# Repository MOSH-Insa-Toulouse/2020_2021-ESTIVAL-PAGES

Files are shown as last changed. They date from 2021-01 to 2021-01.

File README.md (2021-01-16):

# LoRa Project: Smart Gas Sensor

This project is realised in the 5th year PTP ISS at INSA Toulouse. A **LoRa-connected gas sensor** has been developed to alert the user about the concentration of health threatening gas near the sensor.

# Content

This repository contains: 
* KiCad PCB files: A shield for the gas sensor to plug on an Arduino Uno (made with KiCad)
* The datasheet: Complete datasheet for the gaz sensor

## KiCad PCB Files

### Overview
The shield is composed of :

* A home-made gas sensor (made at AIME)
* An amplifier stage for home-made gas sensor
* A commercial gas sensor for the calibration of the home-made one (Grove connectors)
* A LoRa chip for the data transmission
* A LED as an on/off indicator

### Schematics
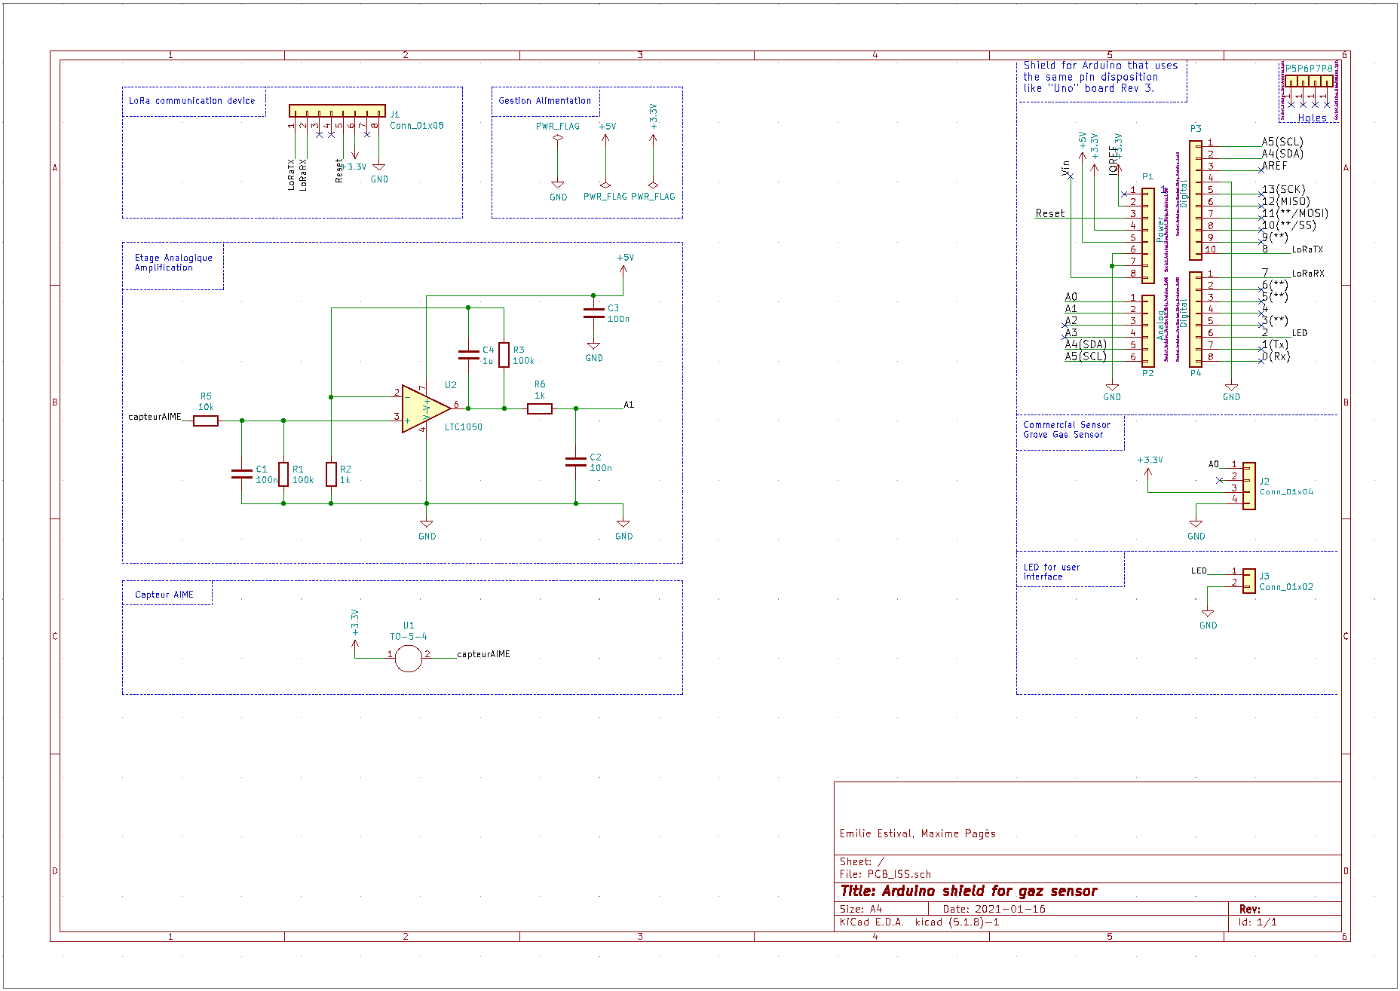
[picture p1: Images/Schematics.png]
Schematics


### PCB Layout
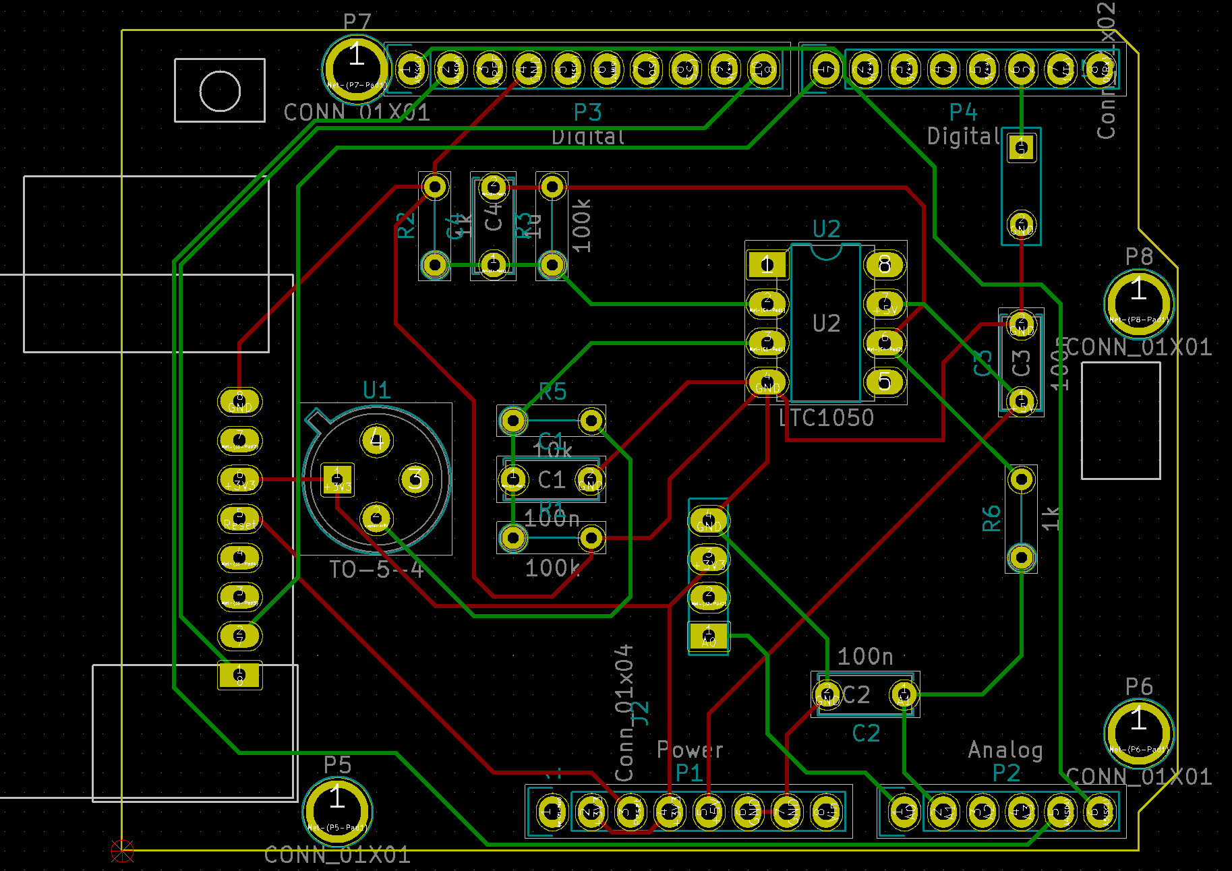
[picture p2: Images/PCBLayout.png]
PCB


### PCB Visualisation
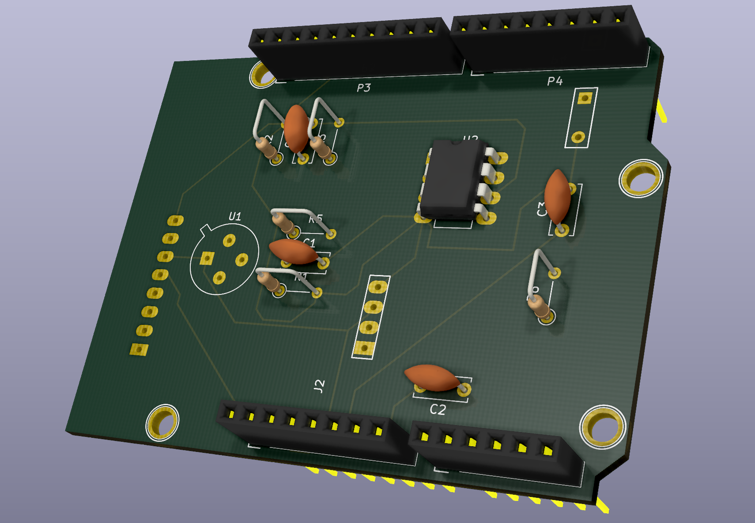
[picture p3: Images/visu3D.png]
Visu3D


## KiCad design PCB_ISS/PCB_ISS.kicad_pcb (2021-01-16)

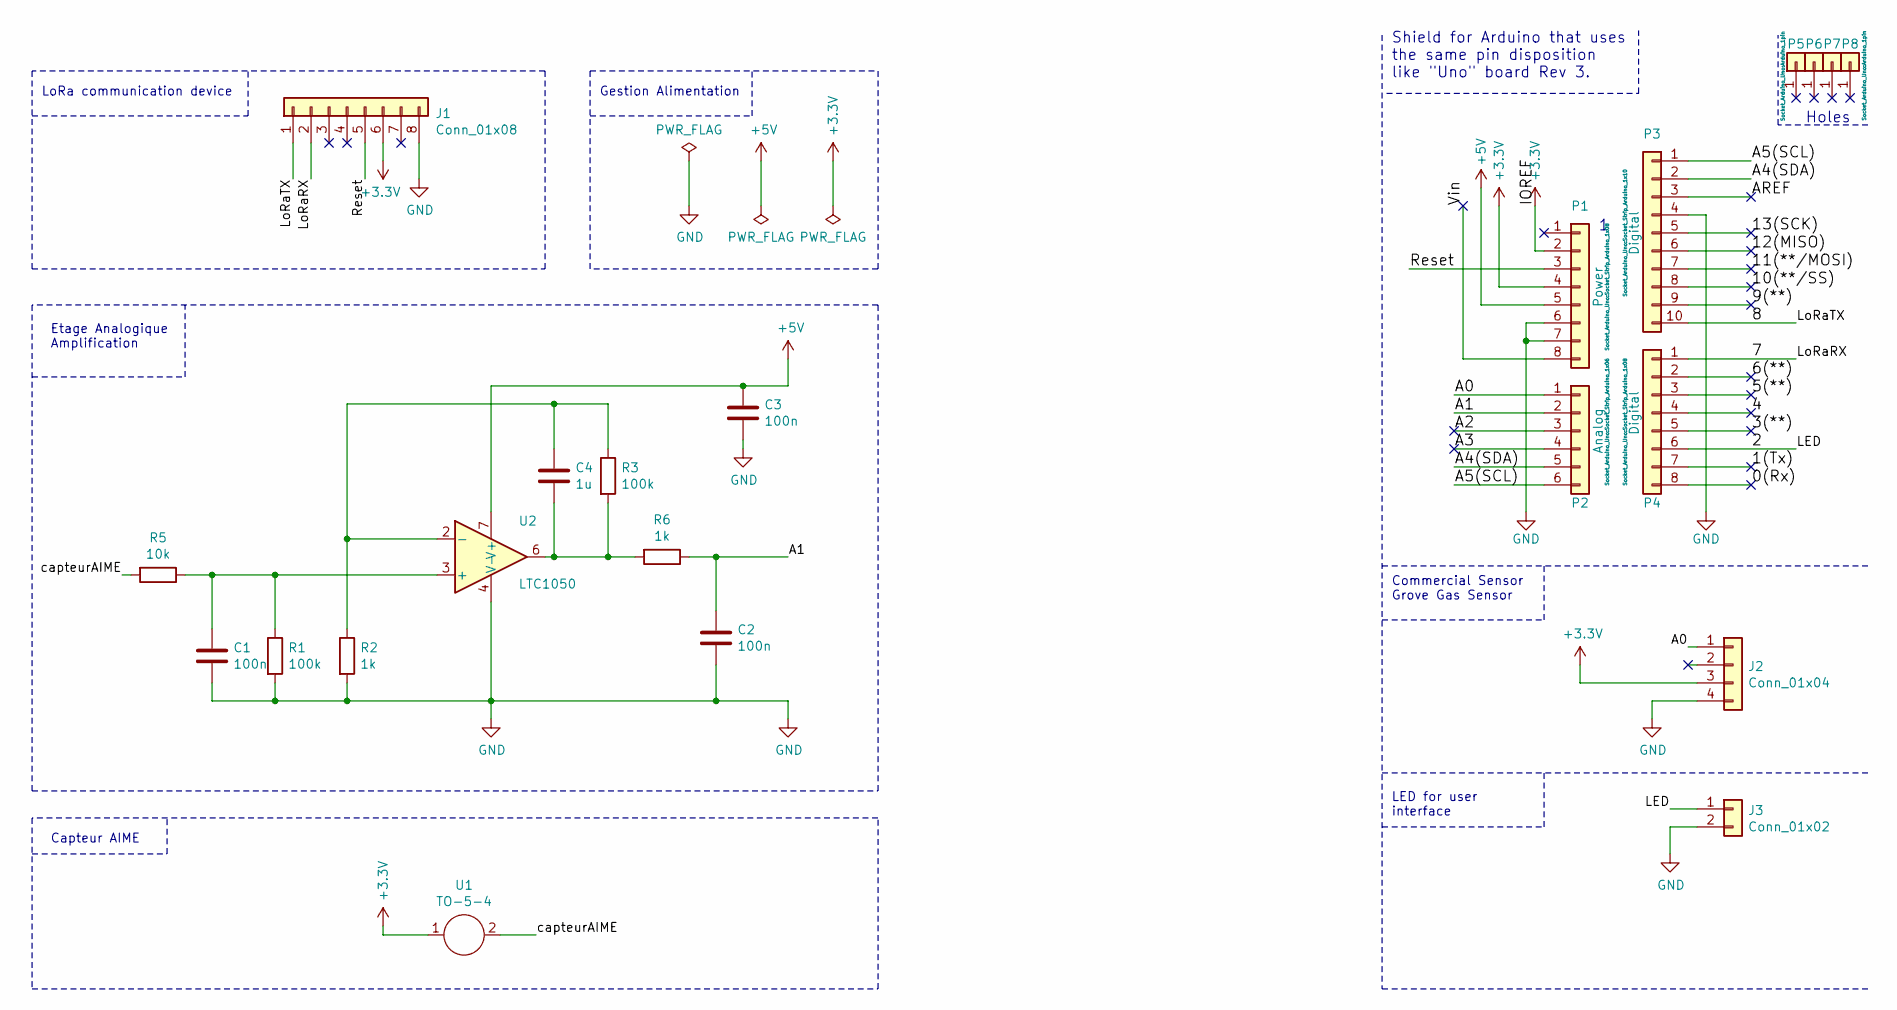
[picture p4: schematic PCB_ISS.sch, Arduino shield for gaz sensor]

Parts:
C1, C2, C3: 100n; C_Disc_D6.0mm_W2.5mm_P5.00mm
C4: 1u; C_Disc_D6.0mm_W2.5mm_P5.00mm
J1: Conn_01x08; Module_RN2483_Breakout_WITHOUTPADS
J2: Conn_01x04; conn_Grove
J3: Conn_01x02; conn_LED
P1: Power; Socket_Strip_Arduino_1x08
P2: Analog; Socket_Strip_Arduino_1x06
P3: Digital; Socket_Strip_Arduino_1x10
P4: Digital; Socket_Strip_Arduino_1x08
P5, P6, P7, P8: CONN_01X01; Arduino_1pin
R1, R3: 100k; R_Axial_DIN0204_L3.6mm_D1.6mm_P5.08mm_Vertical
R2, R6: 1k; R_Axial_DIN0204_L3.6mm_D1.6mm_P5.08mm_Vertical
R5: 10k; R_Axial_DIN0204_L3.6mm_D1.6mm_P5.08mm_Vertical
U1: TO-5-4
U2: LTC1050; DIP-8_W7.62mm_LongPads

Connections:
+3V3: J1.6, J2.3, P1.2, P1.4, U1.1
+5V: C3.1, P1.5, U2.7 (V+)
/0(Rx): P4.8
/1(Tx): P4.7
/2: J3.1, P4.6
/3(**): P4.5
/4: P4.4
/5(**): P4.3
/6(**): P4.2
/7: J1.2, P4.1
/8: J1.1, P3.10
/9(**): P3.9
/10(**/SS): P3.8
/11(**/MOSI): P3.7
/12(MISO): P3.6
/13(SCK): P3.5
/A0: J2.1, P2.1
/A1: C2.1, P2.2, R6.1
/A2: P2.3
/A3: P2.4
/A4(SDA): P2.5, P3.2
/A5(SCL): P2.6, P3.1
/AREF: P3.3
/Reset: J1.5, P1.3
/Vin: P1.8
/capteurAIME: R5.2, U1.2
GND: C1.2, C2.2, C3.2, J1.8, J2.4, J3.2, P1.6, P1.7, P3.4, R1.2, R2.2, U2.4 (V-)
unnamed: C1.1, R1.1, R5.1, U2.3 (+)
unnamed: C4.1, R2.1, R3.1, U2.2 (-)
unnamed: C4.2, R3.2, R6.2, U2.6

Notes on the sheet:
Holes
Shield for Arduino that uses the same pin disposition like "Uno" board Rev 3.
Etage Analogique Amplification
Commercial Sensor Grove Gas Sensor
LoRa communication device
Gestion Alimentation
Capteur AIME
LED for user interface

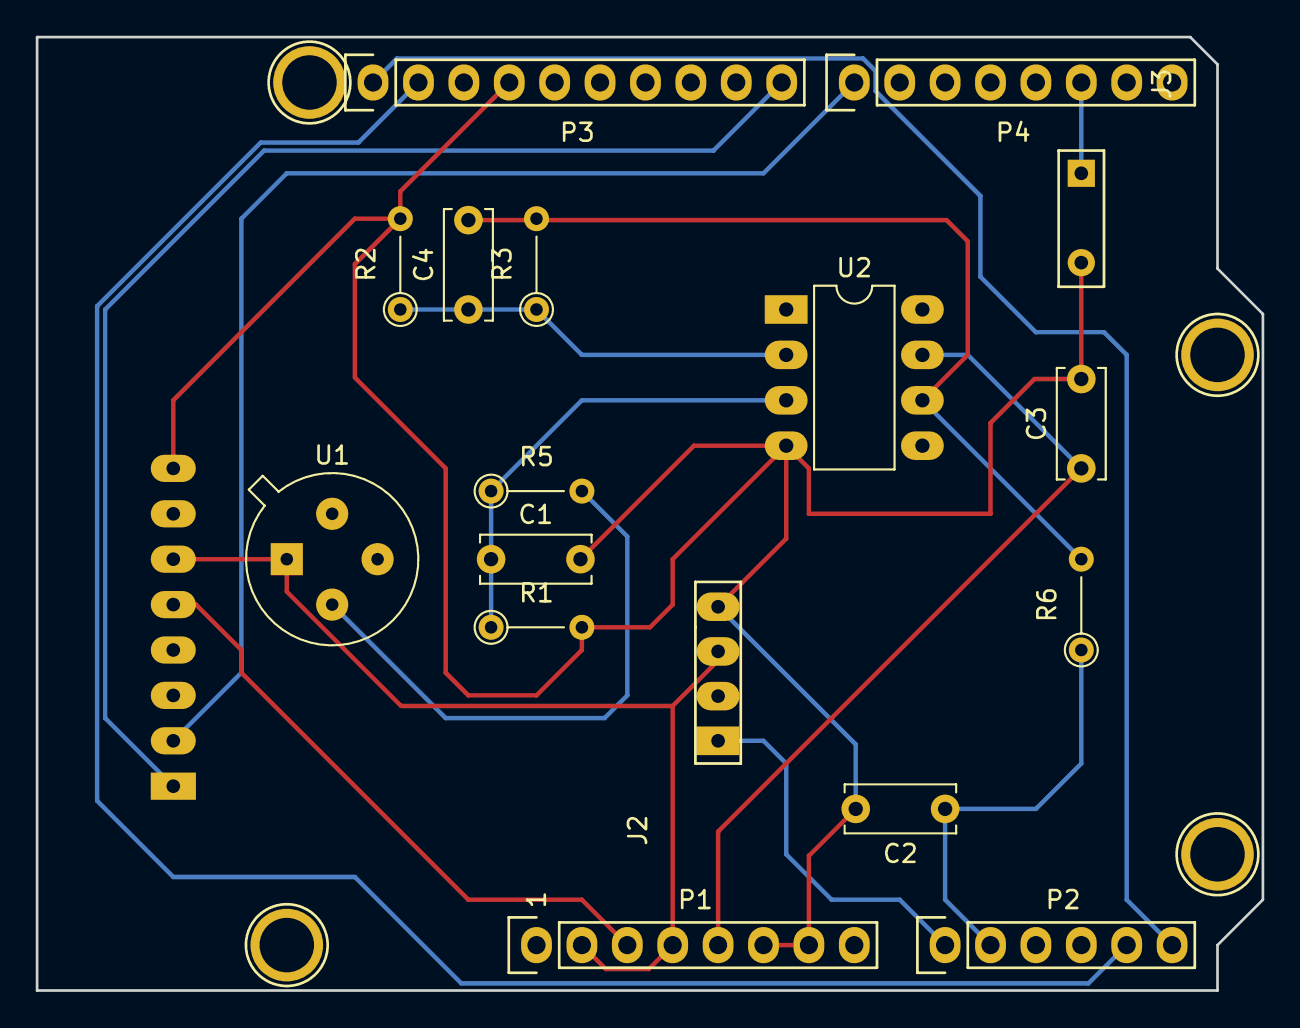
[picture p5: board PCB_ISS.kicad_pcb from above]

Board: 2 copper layers, 68.6 x 53.3 mm, 22 parts (0 on the bottom side), 15 nets.
